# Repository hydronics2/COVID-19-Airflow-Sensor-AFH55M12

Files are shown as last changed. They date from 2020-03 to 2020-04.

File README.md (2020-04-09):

# Airflow Sensor - Automotive Sensor AFH55M12

## Project Description ([from Helpful Engineering](https://www.helpfulengineering.org/))
The intent here is to create a monitoring device, based on a mass airflow meter, that can be used when splitting a ventilator into two or more patients. This will allow staff to monitor individual patients while being controlled by one device in extreme situations where the number of ventilators are not enough to handle the number of patients. The readout should be visible locally on the device and there may need to be parameters input by staff to create a safe operating range and to possibly create alarms when the system is measuring an out of range parameter.

### [Project Requirements](https://docs.google.com/document/d/17Ps910A2vRwnM4EM6F-71GNG1XNa0PaeImd53F7428c/edit?usp=sharing)

This is a quick study of using an inexpensive off-the-shelf automotive airflow type sensor.

Reading from an automotive mass airflow sensor using a microController 12bit ADC, 20ms interval

### --- Updates April 8th -- Assembled PCB, airflow sensor, on 3d print

The model by @john Grano is [here](https://github.com/hydronics2/COVID-19-Airflow-Sensor-AFH55M12/blob/master/3d-prints/MAF_Chamber_Body_V3.stl). Although this appears to prove the technology is working, we're currently pivoting to a manifold type layout...
- to centralize all user interface displays next to the mechanical ventilator
- simplifies to one PCB
- one power supply
- serves multiple flow sensors
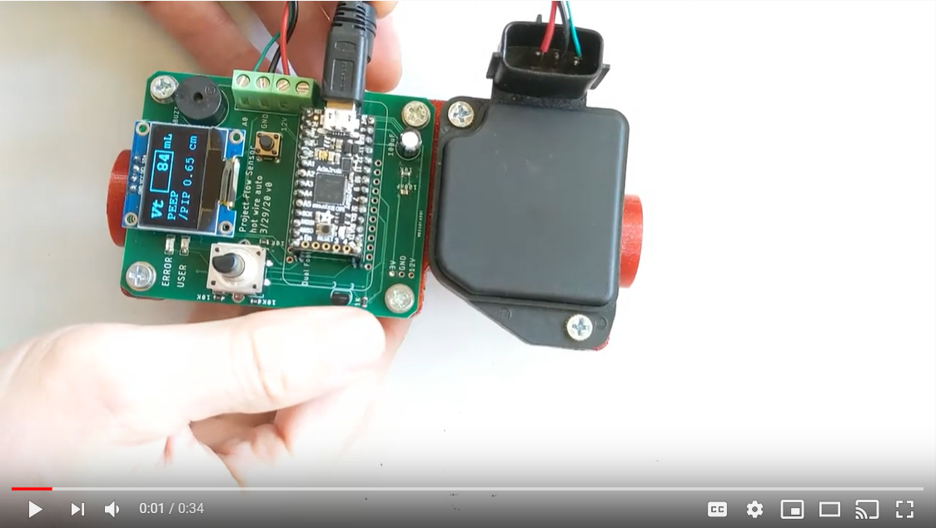
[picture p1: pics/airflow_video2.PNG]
Foo (https://youtu.be/e5O91pYZDbE)


### --- Updates April 6th -- 3D print by @john Grano on Slack

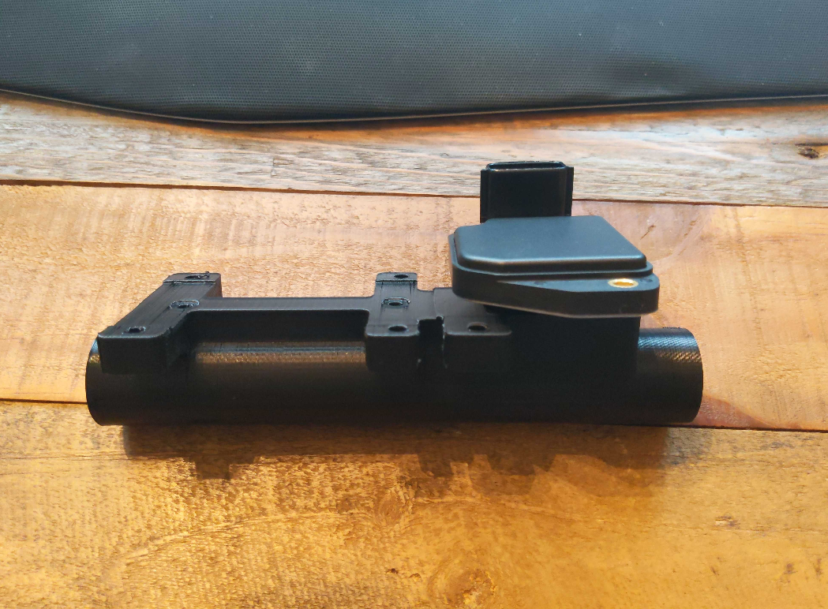
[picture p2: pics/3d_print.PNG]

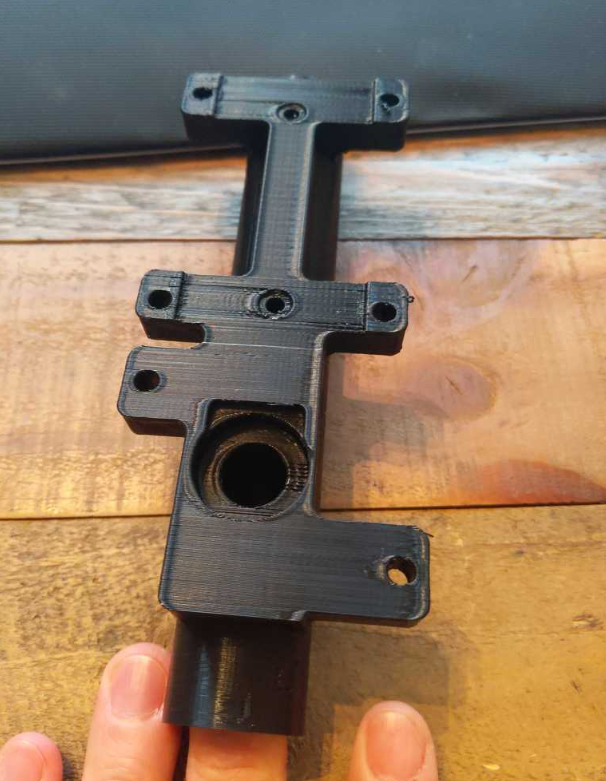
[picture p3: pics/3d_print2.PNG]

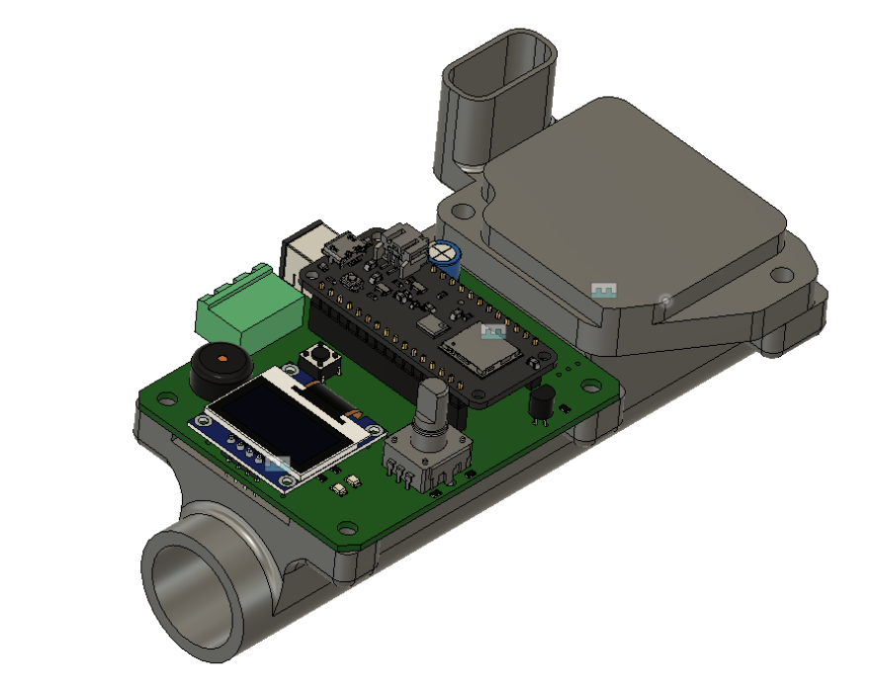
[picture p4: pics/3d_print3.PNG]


###  --- Updates April 4th -- Arduino Sketch show airflow
The arduino sketch shows estimated ariflow volume in mL.

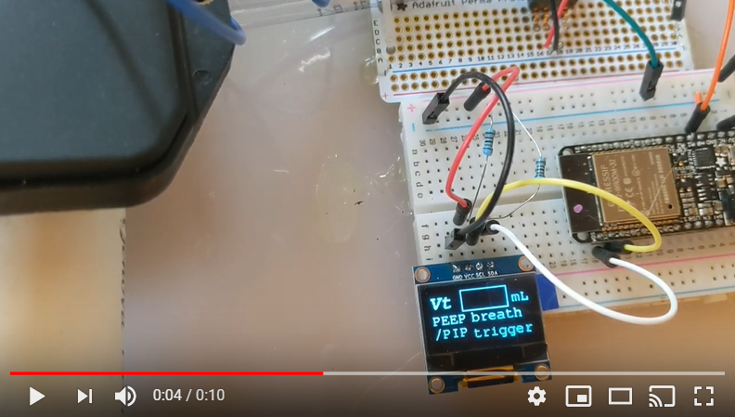
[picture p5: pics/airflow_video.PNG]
Foo (https://youtu.be/0604_5CF9F4)


###  --- Updates Wednesday March 28th -- Airflow testing

Installed sensor in a 1" tube. Only showing inhales
- used previous estimates for a medium inhale breath as ~1150mL to calibrate sensor

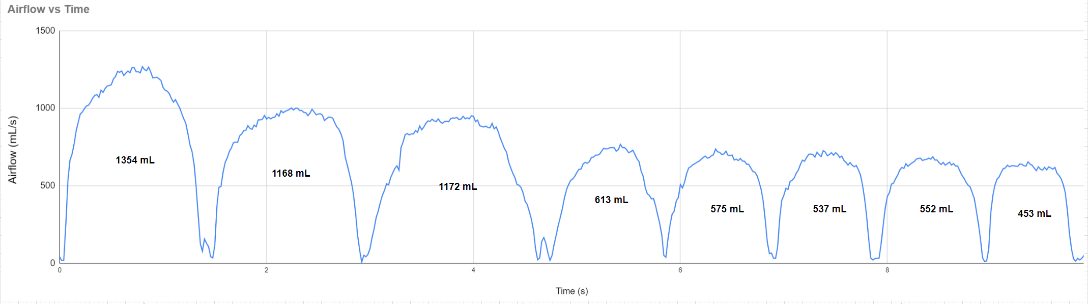
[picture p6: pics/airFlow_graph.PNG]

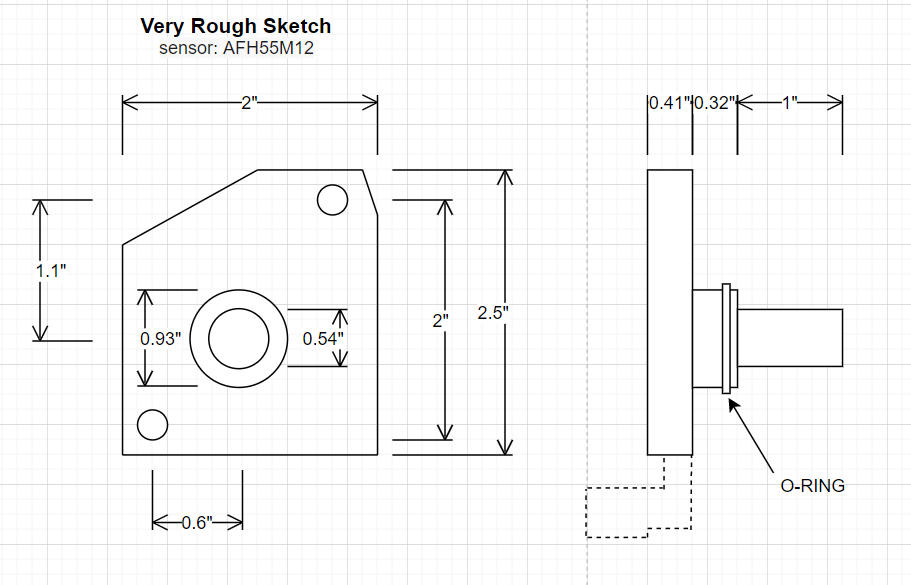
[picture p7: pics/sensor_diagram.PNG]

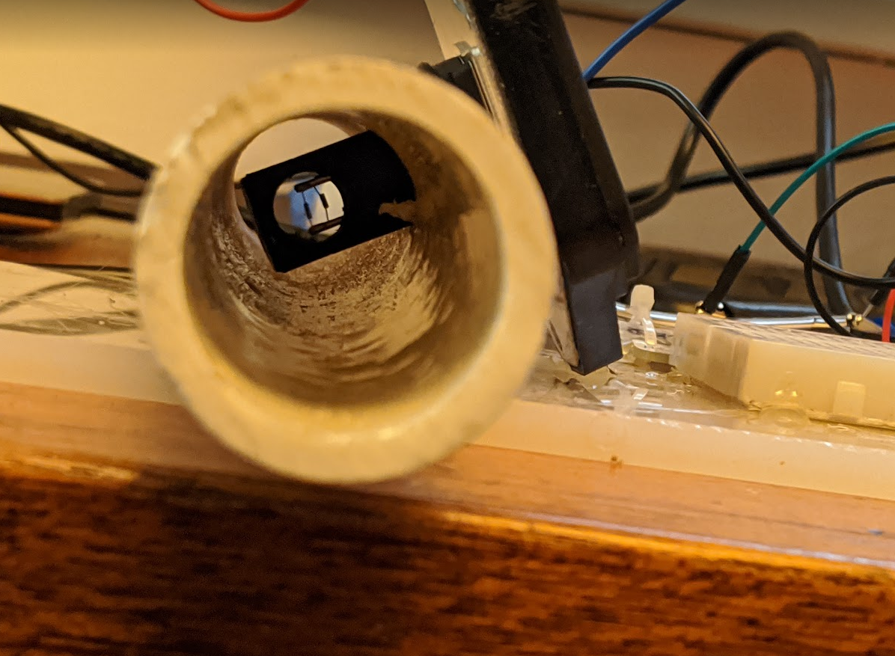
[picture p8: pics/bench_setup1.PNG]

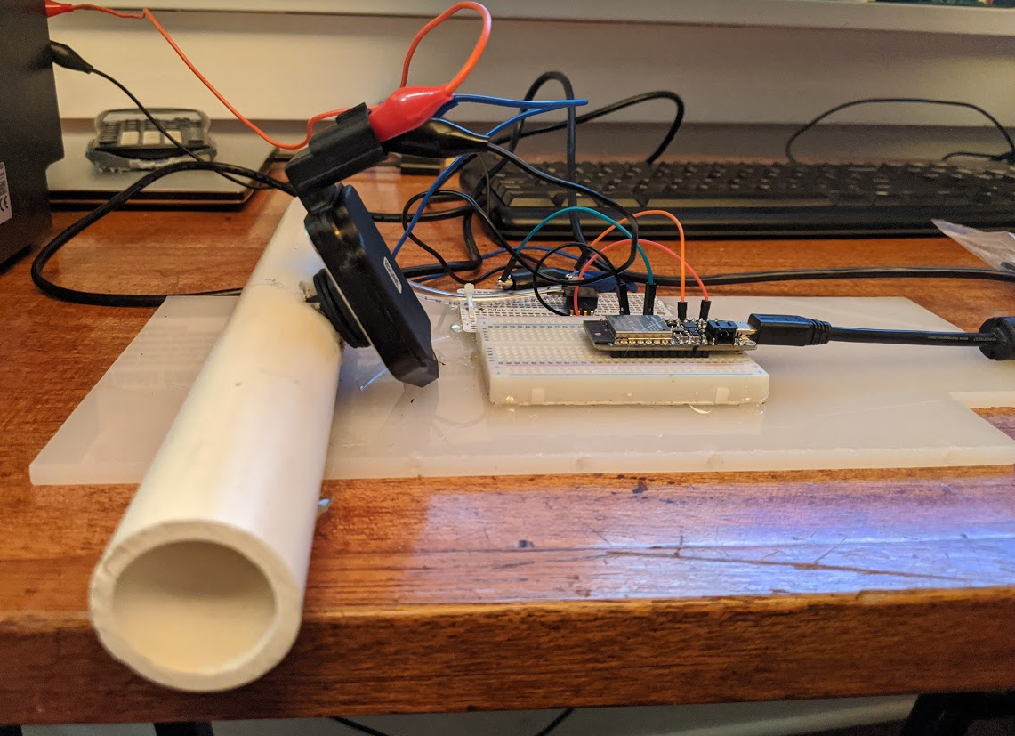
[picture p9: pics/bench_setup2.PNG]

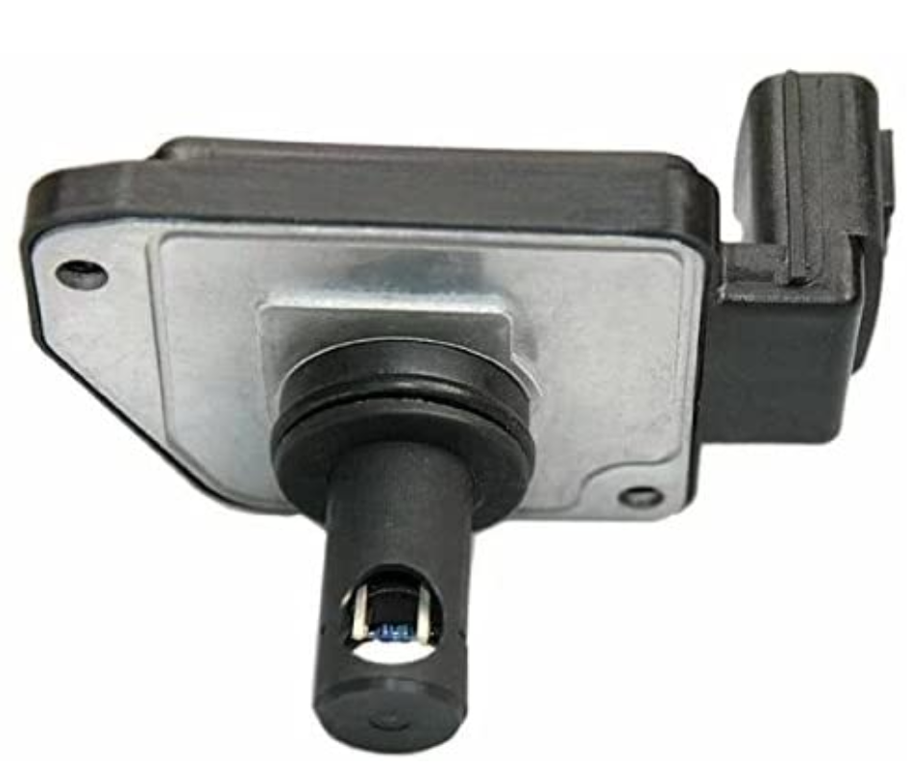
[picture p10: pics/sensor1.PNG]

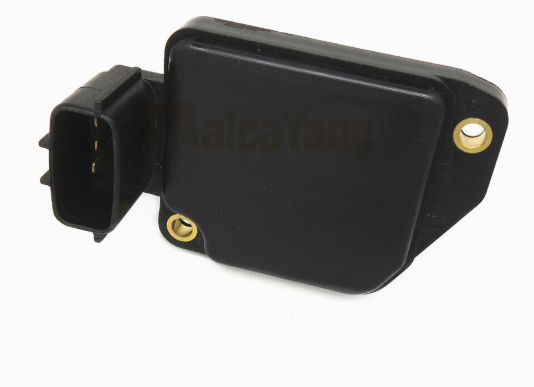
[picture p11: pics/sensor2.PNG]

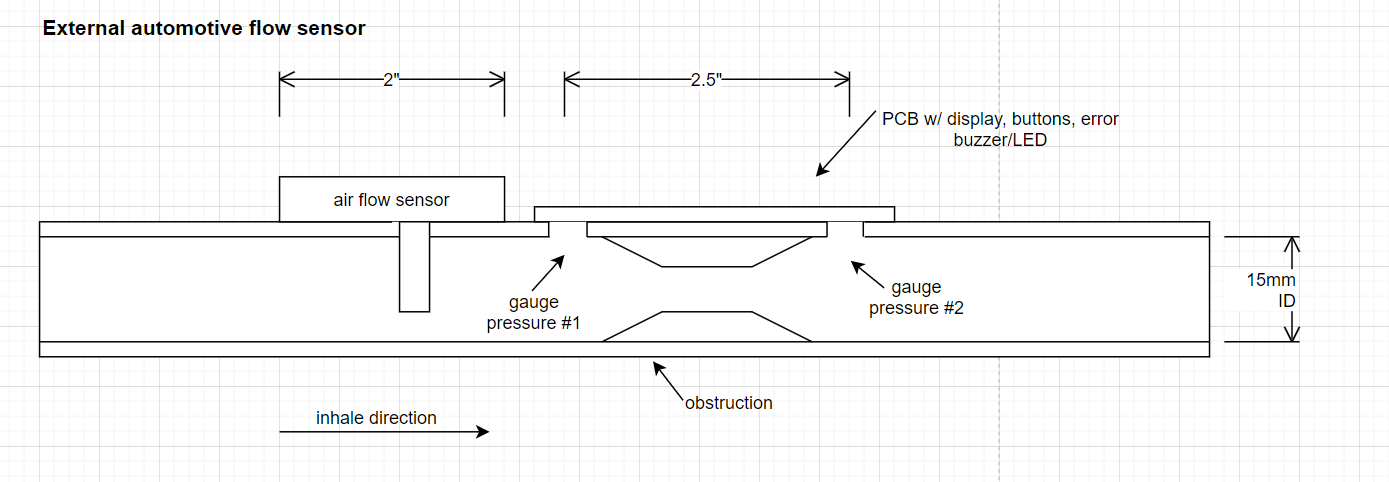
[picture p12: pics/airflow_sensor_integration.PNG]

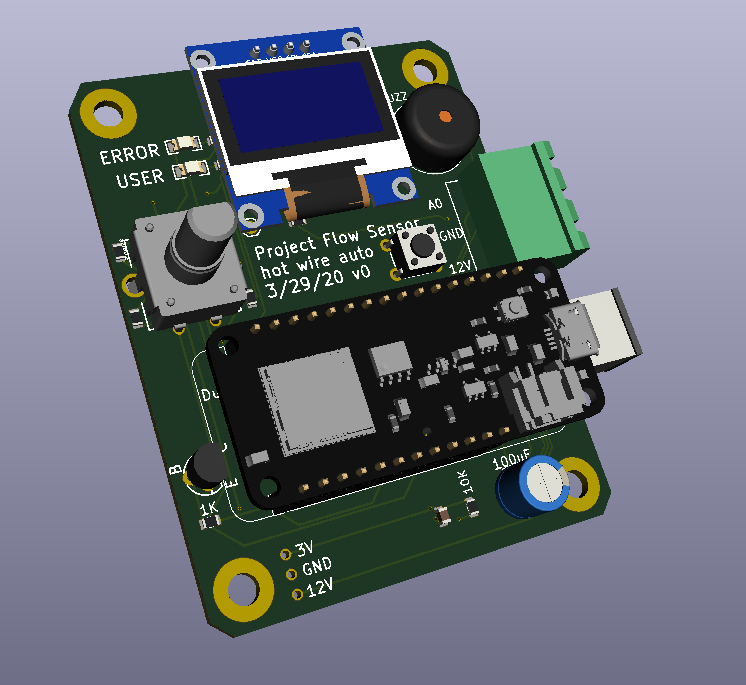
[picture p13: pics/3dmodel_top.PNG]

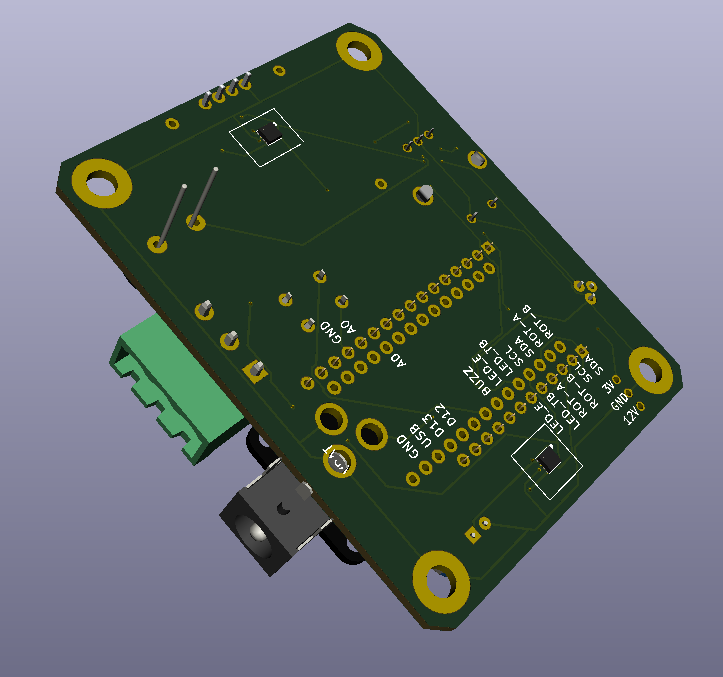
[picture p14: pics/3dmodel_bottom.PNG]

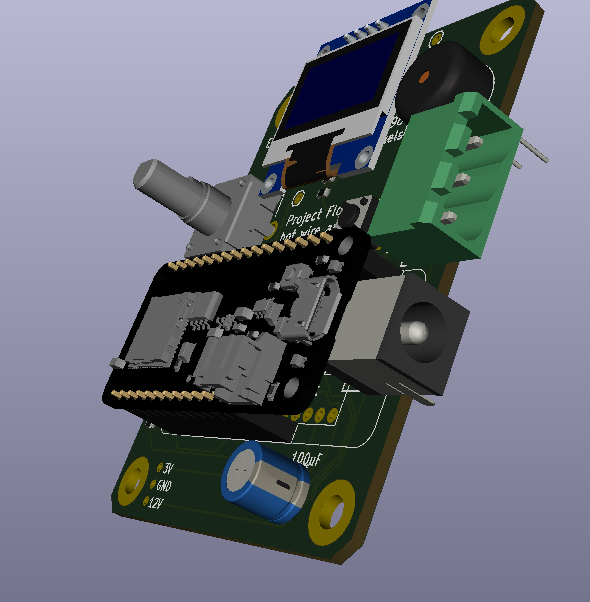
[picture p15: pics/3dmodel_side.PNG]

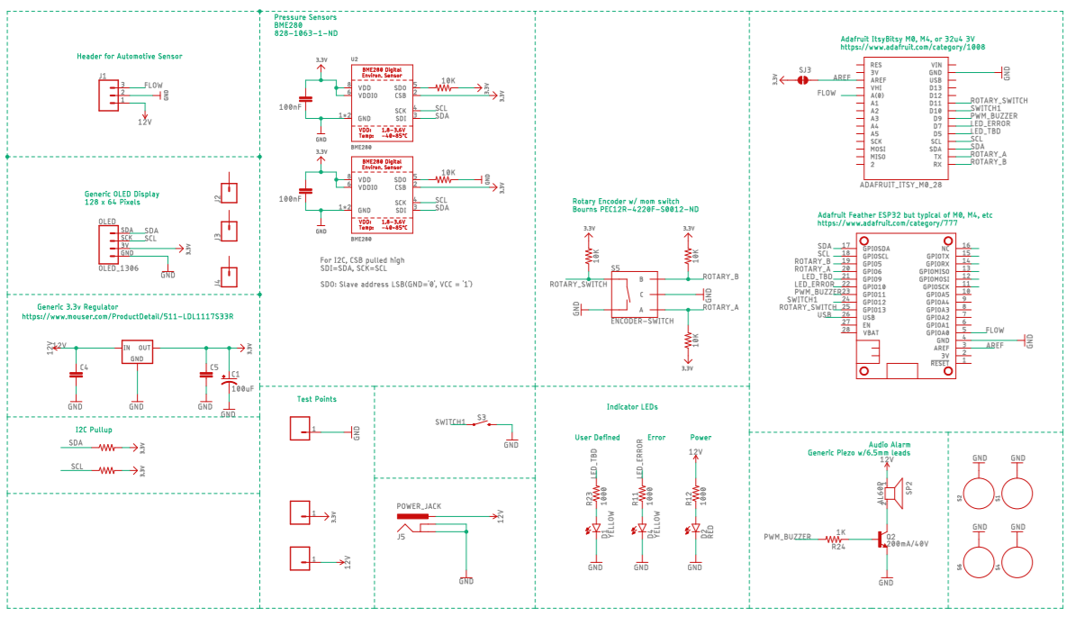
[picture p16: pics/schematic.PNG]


### Sensor Availability
The sensor shows up as multiple part values. It fits a 1998 Nissan/Datsun Truck Frontier 2WD 2.4L FI 4cyl among other years and other vehicles.
- [China](https://www.aliexpress.com/item/32989444018.html?spm=a2g0o.cart.0.0.74dd3c00g1XL5u&mp=1)
- [US Supplier](https://www.amazon.com/gp/product/B074FZMGWG/ref=ppx_yo_dt_b_asin_title_o00_s00?ie=UTF8&psc=1)
- [local supplier oreilly](https://www.oreillyauto.com/search/1998/nissan/frontier?q=MF21219)
- [local supplier auto-zone](https://www.autozone.com/engine-management/mass-air-flow-sensor/duralast-new-mass-air-flow-sensor-dl-3025/337334_0_4995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)

#### Pinout
- Pin A - Empty
- Pin B - 7-12V DC, 90-115mA
- Pin C - Ground
- Pin D Signal

#### Parts List
- oled display is a generic [0.96" 128X64 I2C OLED](https://www.ebay.com/sch/i.html?_from=R40&_trksid=m570.l1313&_nkw=0.96%22+128X64+I2C+OLED&_sacat=0)
- BME280 pressure sensor [828-1063-1-ND](https://www.digikey.com/product-detail/en/bosch-sensortec/BME280/828-1063-1-ND/6136314)

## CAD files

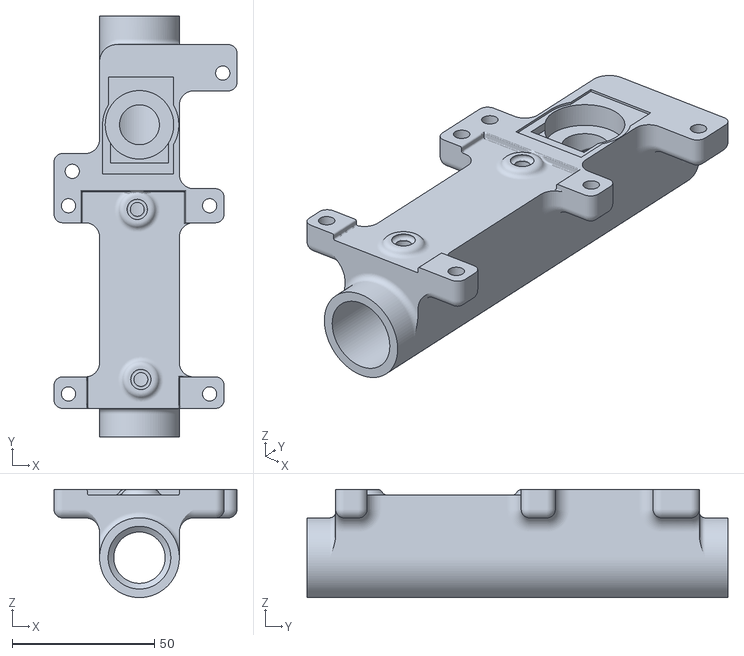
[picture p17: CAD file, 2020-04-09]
3d-prints/MAF_Chamber_Body_V3.stl
64.2 x 147.7 x 38.0

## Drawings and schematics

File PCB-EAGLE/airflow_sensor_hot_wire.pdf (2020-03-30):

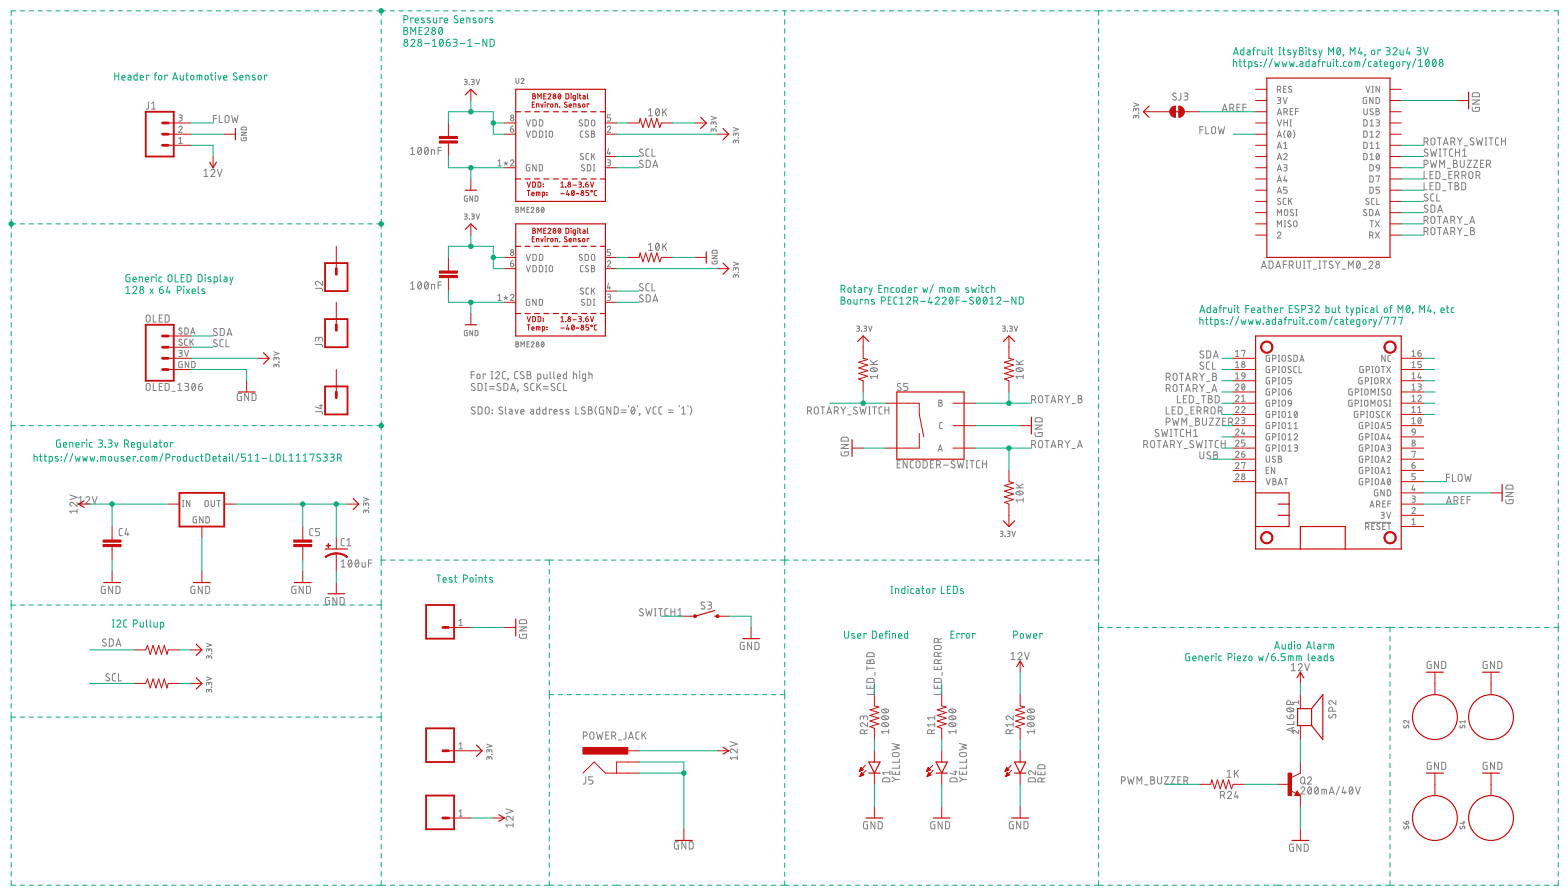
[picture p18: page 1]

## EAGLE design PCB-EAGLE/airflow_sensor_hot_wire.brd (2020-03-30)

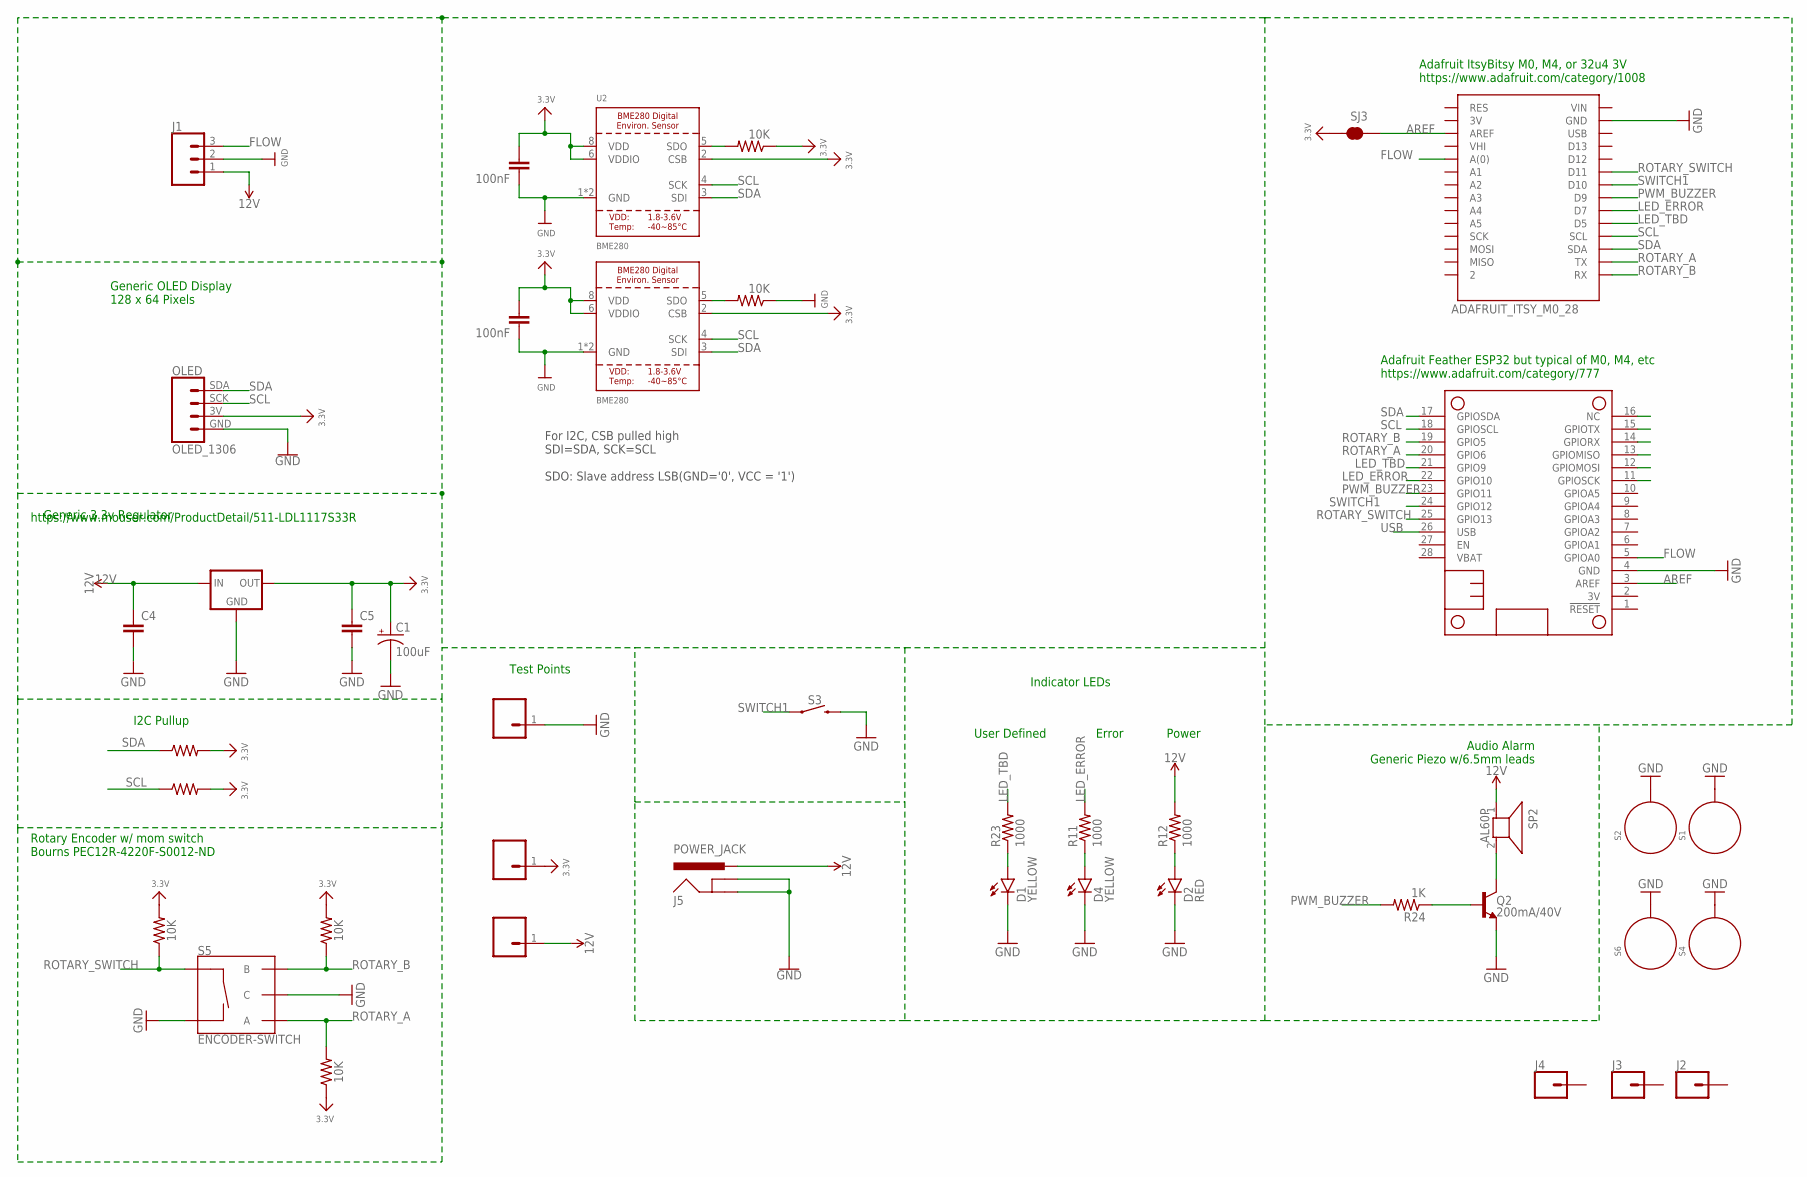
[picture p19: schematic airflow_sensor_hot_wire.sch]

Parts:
3V_REGULATOR: LDL1117_5V_REG; SOT223
C1: 100uF; CPOL-RADIAL-2.5MM-6.5MM
C4, C5: CAP-0805; 0805
C10, C12: 100nF; 0805
D1, D4: YELLOW; LED-1206
D2: RED; LED-1206
J1: CONN_03-SCREW-5MM; SCREWTERMINAL-5MM-3
J2, J3, J4: CONN_01; 1X01
J5: POWER_JACK; POWER_JACK_PTH
MS2: FEATHERWING_NODIM; FEATHERWING_DIM
Q2: 200mA/40V; TO-92
R1, R2, R26, R27, R28: 10K; 0805
R11, R12, R23: 1000; 0805
R21, R22: 0.3; 0805
R24: 1K; 0805
S1, S2, S4, S6: STANDOFF_ELECTRICAL5-32; STANDOFF_ELECTRICAL_5_32
S3: MOMENTARY-SWITCH-SPST-PTH-6.0MM-KIT; TACTILE_SWITCH_PTH_6.0MM_KIT
S5: ENCODER-SWITCH; ROTARY_ENC_PLAIN
SJ3: PWR-LED; PAD-JUMPER-2-NC_BY_TRACE_NO_SILK
SP2: AL60P
U2, U4: BME280
U$1: OLED_1306
U$20, U$31, U$40: CONN_0138MILL; 1X01-40MILL
U$45: ADAFRUIT_ITSY_M0_28; ADAFRUIT_ITS_MO_28

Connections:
3.3V: 3V_REGULATOR.2 (OUT), 3V_REGULATOR.4 (OUT), C1.1 (+), C5.1, C10.1, C12.1, R2.1, R21.2, R22.2, R26.2, R27.1, R28.2, SJ3.2, U2.2 (CSB), U2.6 (VDDIO), U2.8 (VDD), U4.2 (CSB), U4.6 (VDDIO), U4.8 (VDD), U$1.3V (VCC), U$20.1
12V: 3V_REGULATOR.3 (IN), C4.1, J1.1, J5.PWR, R12.2, SP2.1, U$40.1
AREF: MS2.3 (AREF), SJ3.1, U$45.AREF
FLOW: J1.3, MS2.5 (GPIOA0), U$45.A0 (A(0))
GND: 3V_REGULATOR.1 (GND), C1.2 (-), C4.2, C5.2, C10.2, C12.2, D1.C, D2.C, D4.C, J1.2, J5.GND, J5.GNDBREAK, MS2.4 (GND), Q2.1 (E), R1.1, S1.P1, S2.P1, S3.3 (2), S4.P1, S5.C, S5.SW-, S6.P1, U2.1 (GND), U2.7 (GND), U4.1 (GND), U4.7 (GND), U$1.GND, U$31.1, U$45.GND
LED_ERROR: MS2.22 (GPIO10), R11.2, U$45.D7
LED_TBD: MS2.21 (GPIO9), R23.2, U$45.D5
unnamed: D2.A, R12.1
unnamed: D1.A, R23.1
unnamed: R1.2, U4.5 (SDO)
unnamed: R2.2, U2.5 (SDO)
unnamed: Q2.3 (C), SP2.2
unnamed: Q2.2 (B), R24.1
unnamed: D4.A, R11.1
PWM_BUZZER: MS2.23 (GPIO11), R24.2, U$45.D9
ROTARY_A: MS2.20 (GPIO6), R27.2, S5.A, U$45.TX
ROTARY_B: MS2.19 (GPIO5), R26.1, S5.B, U$45.RX
ROTARY_SWITCH: MS2.25 (GPIO13), R28.1, S5.SW+, U$45.D11
SCL: MS2.18 (GPIOSCL), R22.1, U2.4 (SCK), U4.4 (SCK), U$1.SCK, U$45.SCL
SDA: MS2.17 (GPIOSDA), R21.1, U2.3 (SDI), U4.3 (SDI), U$1.SDA, U$45.SDA
SWITCH1: MS2.24 (GPIO12), S3.1, U$45.D10
USB: MS2.26 (USB)

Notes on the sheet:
I2C Pullup
Generic OLED Display 128 x 64 Pixels
Adafruit ItsyBitsy M0, M4, or 32u4 3V https://www.adafruit.com/category/1008
Adafruit Feather ESP32 but typical of M0, M4, etc https://www.adafruit.com/category/777
Test Points
Indicator LEDs
Power
Error
User Defined
Audio Alarm Generic Piezo w/6.5mm leads
Rotary Encoder w/ mom switch Bourns PEC12R-4220F-S0012-ND
Generic 3.3v Regulator
https://www.mouser.com/ProductDetail/511-LDL1117S33R
For I2C, CSB pulled high SDI=SDA, SCK=SCL SDO: Slave address LSB(GND='0', VCC = '1')

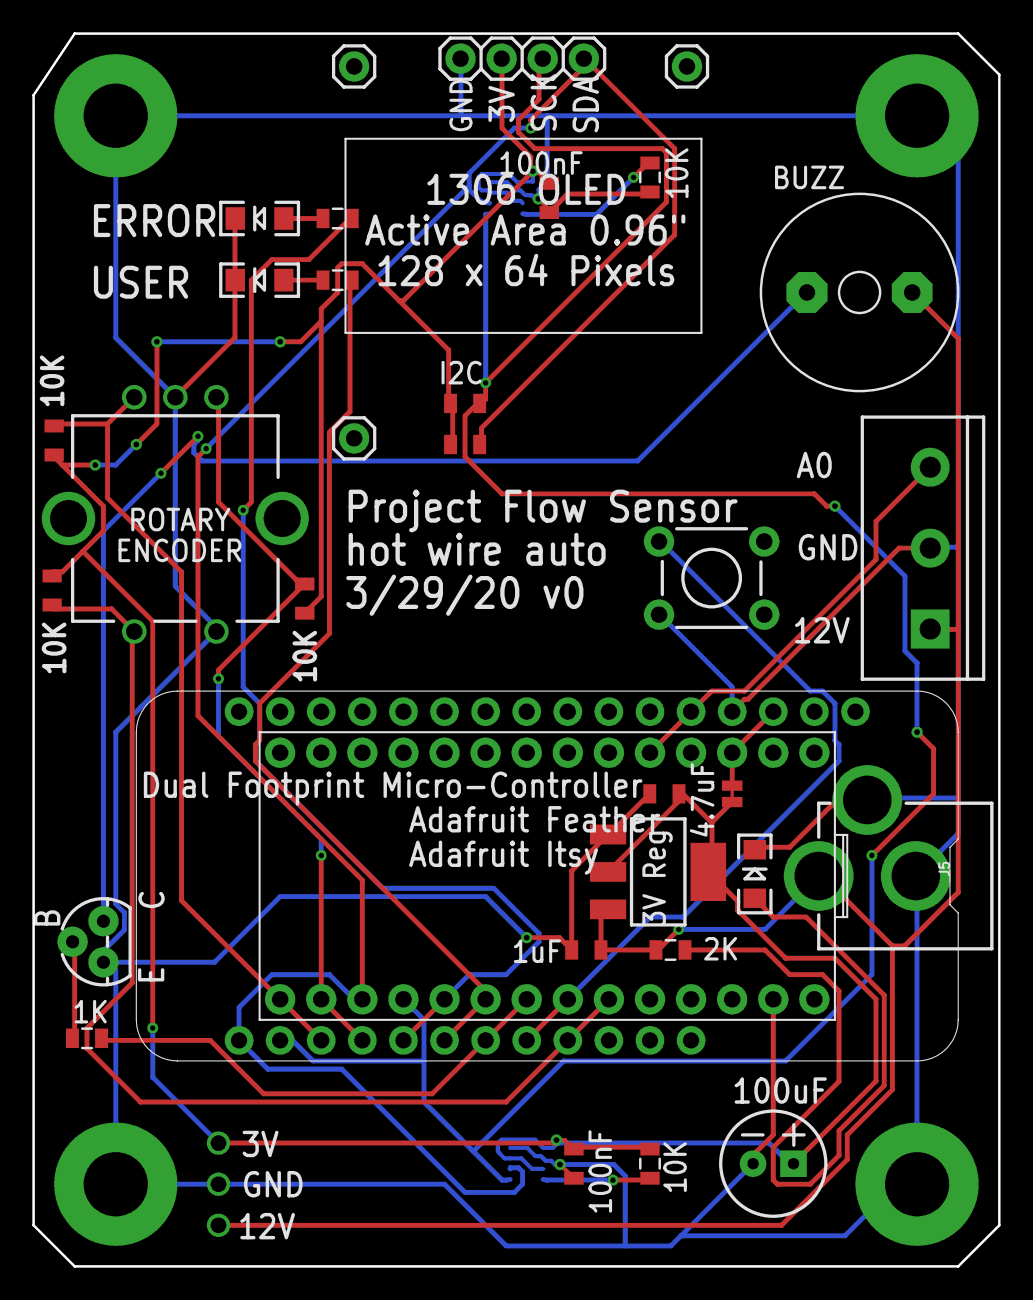
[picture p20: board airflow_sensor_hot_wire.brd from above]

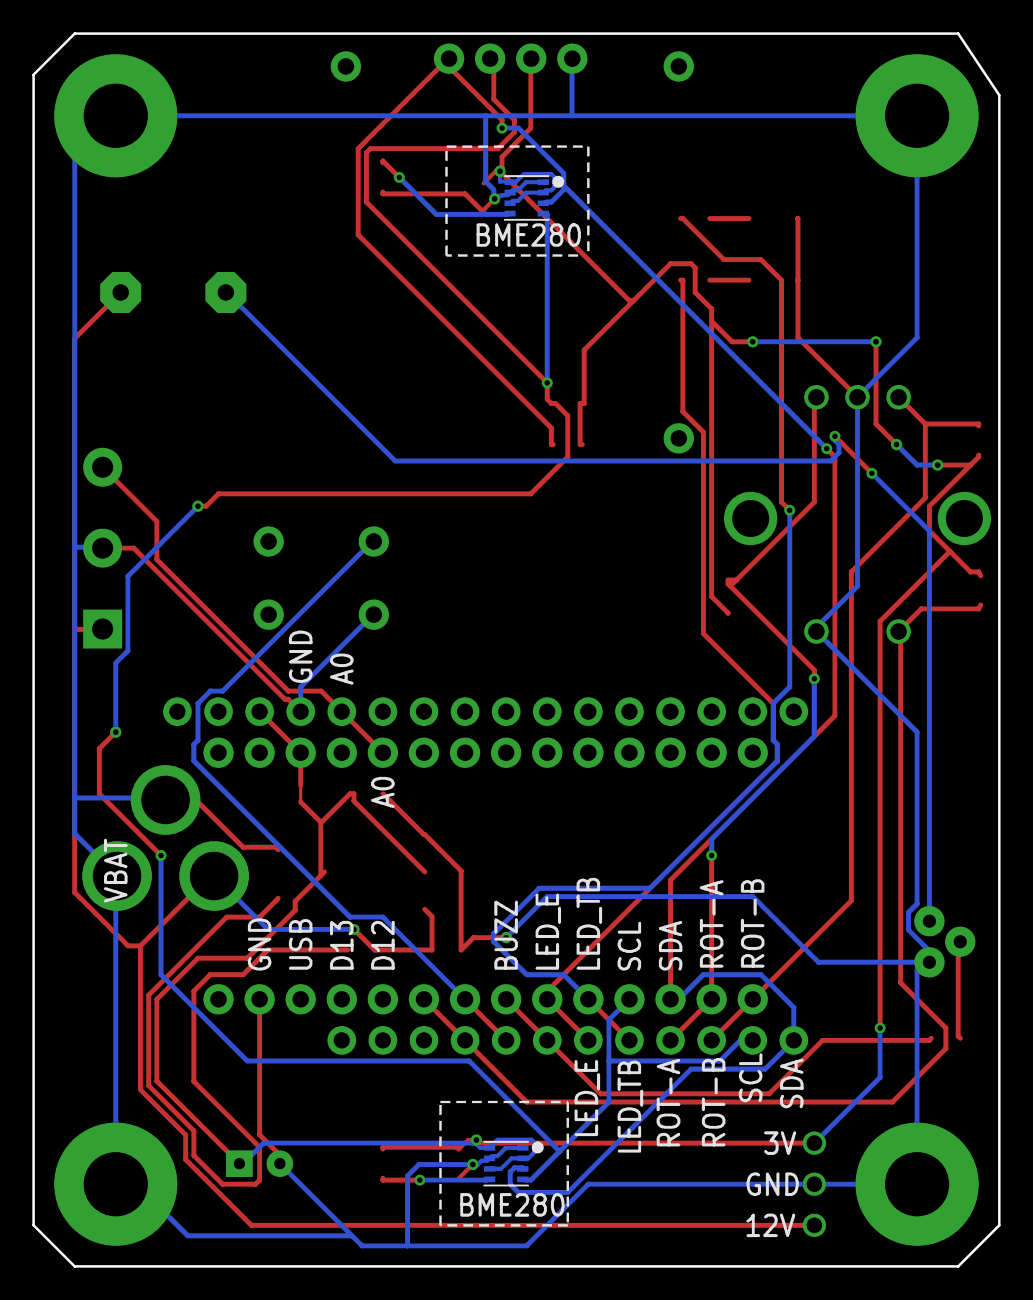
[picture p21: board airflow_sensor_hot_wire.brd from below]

Board: 2 copper layers, 59.7 x 76.2 mm, 42 parts (2 on the bottom side), 21 nets.

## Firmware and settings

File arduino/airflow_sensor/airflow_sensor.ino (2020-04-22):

/*
 * 
 * https://github.com/hydronics2/COVID-19-Airflow-Sensor-AFH55M12
 * 
 * PCB accepts dual footprint feather ESP32 and Adafruit ItsyBitsy M0
 * 
 * 
 * //4/15/20 - added SLM output
 * //4/21/20 - adjusted with Patrick's curve fit calbration equation.
 * //4/21/20 - added one ms to the volume calculation


*/

#include <Wire.h>
#include <SPI.h>
#include <Adafruit_Sensor.h> // https://github.com/adafruit/Adafruit_Sensor
#include <Adafruit_BME280.h> //https://github.com/adafruit/Adafruit_BME280_Library

#include <Adafruit_GFX.h>  // https://github.com/adafruit/Adafruit-GFX-Library
#include <Adafruit_SSD1306.h>  // https://github.com/adafruit/Adafruit_SSD1306
#include <avr/dtostrf.h> //for converting from an integer to a string for the display
Adafruit_SSD1306 display(128, 64);  // Create display


#include <Fonts/FreeMonoBold12pt7b.h>  // Add a custom font
#include <Fonts/FreeMonoBoldOblique12pt7b.h>
#include <Fonts/FreeMono9pt7b.h>  // Add a custom font


#define atmosphericPressure 101625 //need a number (Pascals) here to evaluate BME280... may need a BME280 sensor on the top of the board to get atomospheric

Adafruit_BME280 bme1; // I2C pressure sensor under the display
Adafruit_BME280 bme2; // I2C pressure sensor on the bottom of the board

//pinouts for Feather esp32
//const int errorLED = 21; //feather esp32
//const int userLED = 22; //feather esp32
//const int buzzer = 23; //feather esp32
//const int encoder0PinA = 19;  //feather esp32
//const int encoder0PinB = 20;  //feather esp32
//const int encoderButton = 25; //feather esp32
//const int userButton = 24; //feather esp32

const int errorLED = 5; //itsybitsy M0
const int userLED = 7; //itsbitsy M0
const int buzzer = 9; //itsybitsy M0
const int encoder0PinA = 0;  //itsybitsy M0
const int encoder0PinB = 1;  //itsybitsy M0
const int encoderButton = 11; //itsybitsy M0
const int userButton = 10; //itsybitsy M0

const int flowSensorPin = A0; 
int flowSensorValue = 0;   

const int sizeBreath = 500;
int arrayBreath[sizeBreath];
int incrementBreath = 0;

//these arrays capture the rolling average (non-breath) sensor value baseline
const int sizeRollingSmall = 10;
int arrayAverageSmall[sizeRollingSmall];
int incrementRollingSmall = 0;

const int sizeRolling = 50;
byte arrayAverage[sizeRolling];
int incrementRolling = 0;

boolean startBreathFlag = false;
boolean breathFlag = false;
int flowSensorThreshold = 1824; //temporary number
int averageSensorValue = 0;
long lastTimeSense;
int senseInterval = 20;

int flowSensorCalibration = 162; //actually number is 0.0162 converts delta ADC into SLM
double timePeriod;

int pressureReading = 0;
float pressureReading2 = 0;

void setup()  // Start of setup
{        
  Serial.begin(115200);
  analogReadResolution(12); //required for SAMD21

  pinMode(errorLED, OUTPUT);
  digitalWrite(errorLED, LOW);
  pinMode(userLED, OUTPUT);
  digitalWrite(userLED, LOW);
  pinMode(buzzer, OUTPUT);
  
  timePeriod = (double)senseInterval/1000; //time period in seconds
  Serial.print("sensing time period(seconds)= ");
  Serial.println(timePeriod);
  Serial.print("calibration factor = ");
  Serial.println(flowSensorCalibration/10000);
  
  delay(100);  // This delay is needed to let the display to initialize
  display.begin(SSD1306_SWITCHCAPVCC, 0x3C);  // Initialize display with the I2C address of 0x3C 
  display.clearDisplay();  // Clear the buffer
  display.setTextColor(WHITE);  // Set color of the text
  display.setRotation(0);  // Set orientation. Goes from 0, 1, 2 or 3
  display.setTextWrap(false);  // By default, long lines of text are set to automatically “wrap” back to the leftmost column.
                               // To override this behavior (so text will run off the right side of the display - useful for
                               // scrolling marquee effects), use setTextWrap(false). The normal wrapping behavior is restored
                               // with setTextWrap(true).
  display.dim(0);  //Set brightness (0 is maximun and 1 is a little dim)

  if (! bme1.begin(0x76, &Wire)) //this is the sensor under the display
  {
    Serial.println("Could not find a valid BME280 sensor, check wiring! for 0x76");
    while (1);
  }
//  if (! bme2.begin(0x77, &Wire)) {
//    Serial.println("Could not find a valid BME280 sensor, check wiring! for 0x77");
//    while (1);
//  }
}  


void loop()  // Start of loop
{
  long now = millis();

  if(now - lastTimeSense > senseInterval)
  {
    flowSensorValue = analogRead(flowSensorPin);
    //Serial.println(flowSensorValue);
    lastTimeSense = now;
    if(flowSensorValue > flowSensorThreshold)
    {
      if(startBreathFlag == false)
      {
        startBreathFlag = true;
        
        incrementBreath = 0;
      }else
      {
        //int SLM = (flowSensorValue - averageSensorValue)*flowSensorCalibration; //converts SLM 
        float SLM = constrain(17.816955 - .029497326 * flowSensorValue + 1.231863E-5 * sq(flowSensorValue),0,100);
        
        Serial.print("time: ");
        Serial.print(now);
        Serial.print(" ms, SLM: ");
        //Serial.println((float)SLM/10000); //converts flow sensor calibration back to correct magnitude for printing
        Serial.println(SLM);
        digitalWrite(userLED, HIGH);     
        if(incrementBreath == 20) 
        {
          breathFlag = true;
          displayBreath();
          digitalWrite(errorLED, HIGH);
          analogWrite(buzzer, 5);
          pressureReading = bme1.readPressure(); //ok lets take a pressure reading now that there is flow
        }
        arrayBreath[incrementBreath] = flowSensorValue;
        incrementBreath++;
        if(incrementBreath == sizeBreath){
          incrementBreath = 0;      
        }
      }
    }else 
    {
      if(breathFlag) //a breath just finished... calculate the volume
      {        
        calculateBreath();
      }
      startBreathFlag = false;
      breathFlag = false;
      digitalWrite(userLED, LOW);
      digitalWrite(errorLED, LOW);
      analogWrite(buzzer, 0);
      arrayAverageSmall[incrementRollingSmall] = flowSensorValue; //keep track of the average no-flow sensor value
      incrementRollingSmall++;
      if(incrementRollingSmall == sizeRollingSmall){               
        incrementRollingSmall = 0;
        int flowSensorSmallAverage = 0;
        for(int i = 0; i< sizeRollingSmall; i++)
        {
          flowSensorSmallAverage = flowSensorSmallAverage + arrayAverageSmall[i];
        }
        flowSensorSmallAverage = flowSensorSmallAverage/sizeRollingSmall;
        arrayAverage[incrementRolling] = flowSensorSmallAverage/10; //make it small enough to fit in a byte array.
        incrementRolling++;
        if(incrementRolling == sizeRolling){
          printAverageSensorValue();
          incrementRolling = 0;      
        }      
      }
    }
  }
}


void calculateBreath()
{
  pressureReading = pressureReading - atmosphericPressure; //subtract current pressure
  pressureReading2 = (float)pressureReading * 0.0101972; //convert to cm of water
  Serial.print("pressure reading: ");
  Serial.println(pressureReading2);

  
  long totalSensorValue = 0;
  for(int i=0; i<sizeRolling; i++)
  {
    totalSensorValue = totalSensorValue + arrayAverage[i];    
  }
  totalSensorValue = totalSensorValue/(sizeRolling);
  averageSensorValue = totalSensorValue*10; // change back into correct magnitude after packaging as a byte
  Serial.println();
  Serial.print("average sensor value: ");
  Serial.println(averageSensorValue);
  float totalBreath = 0;  
  for(int i=0; i<incrementBreath; i++) //evaluate all the flow readings we received over the breath
  {
    //long change = (arrayBreath[i] - averageSensorValue)*flowSensorCalibration*senseInterval*1000/60000; //converts SLM to mL
    float change = (constrain(17.816955-.029497326*arrayBreath[i]+1.231863E-5*sq((float)arrayBreath[i]),0,100))*(senseInterval+1)*1000/60000; //converts SLM to mL
    totalBreath = totalBreath + change;
  }
  Serial.print("increment Breath: "); //this is how many flow samples we evaluated
  Serial.println(incrementBreath);
  Serial.print("volume: "); //this is the total volume of all the flow samples
  //Serial.println((float)totalBreath/10000); //adjust for correct magnitude of calibration factor
  Serial.println(totalBreath);
  //float totalBreath2 = totalBreath/10000;
  updateDisplay(totalBreath);
}  


void updateDisplay(int flowValue)
{
  // Convert flowValue into a string, so we can change the text alignment to the right:
  // It can be also used to add or remove decimal numbers.
  char string[10];  // Create a character array of 10 characters
  char pressure[10];
  // Convert float to a string:
  dtostrf(flowValue, 4, 0, string);  // (<variable>,<amount of digits we are going to use>,<amount of decimal digits>,<string name>)
  
  //floatToString(pressure,pressureReading2,0,7,true);
  //dtostrf(pressureReading2, 4, 0, pressure);

  display.clearDisplay();  // Clear the display so we can refresh

  display.setFont(&FreeMonoBoldOblique12pt7b);  // Set a custom font
  display.setTextSize(0);  // Set text size. We are using a custom font so you should always use the text size of 0
  // Print text:
  display.setCursor(0, 20);  // (x,y)
  display.println("Vt");  // Text or value to print
  // Draw rectangle:
  display.drawRect(40, 0, 60, 27, WHITE);  // Draw rectangle (x,y,width,height,color)
                                           // It draws from the location to down-right   
  display.setFont(&FreeMonoBold12pt7b);  // Set a custom font  
  // Print variable with left alignment:
  display.setCursor(42, 20);  // (x,y)
  display.println(string);  // string for right alignment

  // Print text:
  display.setFont(&FreeMono9pt7b);  // Set a custom font
  display.setCursor(0, 40);  // (x,y)
  display.println("PEEP");  // Text or value to print
  
  // Print text:
  display.setFont(&FreeMono9pt7b);  // Set a custom font
  display.setCursor(0, 57);  // (x,y)
  display.println("/PIP");  // Text or value to print

  // Print mL
  display.setCursor(105, 20);  // (x,y)
  display.println("mL");

  // Print cm
  display.setCursor(105, 57);  // (x,y)
  display.println("cm");

  // Print variable with right alignment:
  display.setCursor(51, 57);  // (x,y)
  display.println(pressureReading2);  // Text or value to print
  display.setCursor(83, 57);  // (x,y)
  //display.println(pressure);  // Text or value to print

  display.display();  // Print everything we set previously
}

void displayBreath()
{

  display.clearDisplay();  // Clear the display so we can refresh
  // Print variable with right alignment:
  display.setCursor(50,40);  // (x,y)
  display.println("breath");  // Text or value to print
  display.setCursor(50,60);  // (x,y)
  display.println("triggered");  // Text or value to print
  display.display();  // Print everything we set previously
}


void printAverageSensorValue()
{
  averageSensorValue = 0;
  for(int i=0; i<sizeRolling; i++)
  {
    averageSensorValue = averageSensorValue + arrayAverage[i];    
  }
  averageSensorValue = averageSensorValue/(sizeRolling);
  averageSensorValue = averageSensorValue*10; // change back into correct magnitude after packaging as a byte
  Serial.println();
  Serial.println();
  Serial.print("average sensor value: ");
  Serial.println(averageSensorValue);

  flowSensorThreshold = averageSensorValue + 200;
}

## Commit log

2020-03-30 add eagle files
    [airflow_sensor_hot_wire.brd, airflow_sensor_hot_wire.sch]
2020-03-30 schematic update
    [airflow_sensor_hot_wire.sch]
2020-04-05 added arduino sketch and video
2020-04-06 added stl
2020-04-09 added 3d print file
    [MAF Chamber Body V3.stl]
2020-04-09 updates names
    [MAF_Chamber_Body_V3.stl]
2020-04-22 updated with curve fit calibration equation for SLM

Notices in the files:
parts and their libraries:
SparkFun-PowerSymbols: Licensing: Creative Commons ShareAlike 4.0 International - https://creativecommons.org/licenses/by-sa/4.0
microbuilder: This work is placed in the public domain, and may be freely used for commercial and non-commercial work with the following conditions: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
